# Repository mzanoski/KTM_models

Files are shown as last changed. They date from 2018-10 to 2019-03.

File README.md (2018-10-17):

# KTM 1290 OpenScad Models
This repo contains 3d models for 2017 KTM 1290 Super Adventure R accessories.  

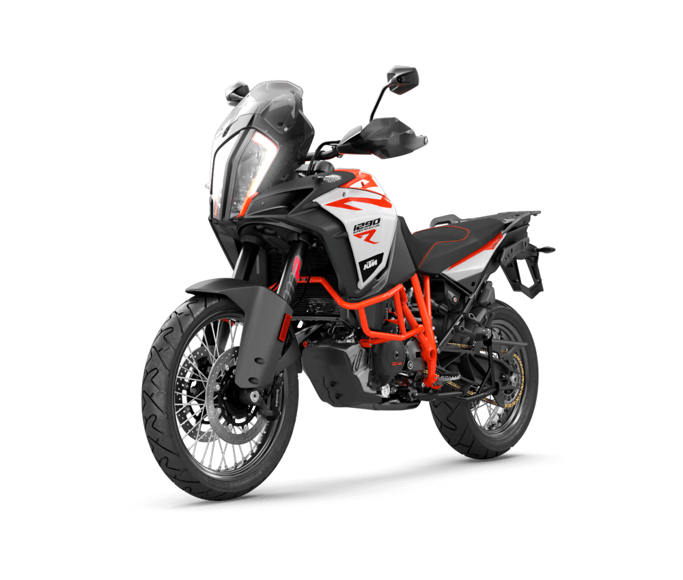
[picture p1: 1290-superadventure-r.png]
2017 KTM 1290 Super Adventure R Image


## Models
[Dash Accessory Bar](docs/dash_accessory_bar.md)\
[Dash GoPro Mount](docs/dash_gopro_mount.md)

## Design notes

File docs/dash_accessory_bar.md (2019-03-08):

# Dash Accessory Bar
This is an attachment with a grooved bar that can be attached to windshield bolt mounts above the dash screen.

## Definitions
These terms are used in scad file and are important for understanding parameters and how to make changes to your model.

| Item | Description |
| --- | --- |
| __Adapter__ | Conic portion of the attachment that is bolted to the top of the windscreen post |
| __Bar__ | Cylinder that stretches between the two windscreen mounts |
| __Bar Inner Hole__ | The hole inside of the bar used to insert aluminum tube or rod for additional strength |
| __Washer__ | Circle with a hole on the bolt side of the adapter |
| __End-Cap__ | Circle that covers the rider side of the adapter |
| __Cone__ | Conic shape between the washer and end-cap |
| __Anti-Roll Hole__ | Hole through the entire accessory bar for a pin that will prevent the bar from rolling |
| __Rick Bar__ | Grooved portion of the cylinder of the adapter |
| __Wall Thickness__ | Thickness of the washer, cone, and end-cap walls |
| __Margin__ | Tollerance added to windshield post side of the adapter and bar inner hole |

| Adapter | Bar |
| --- | --- |
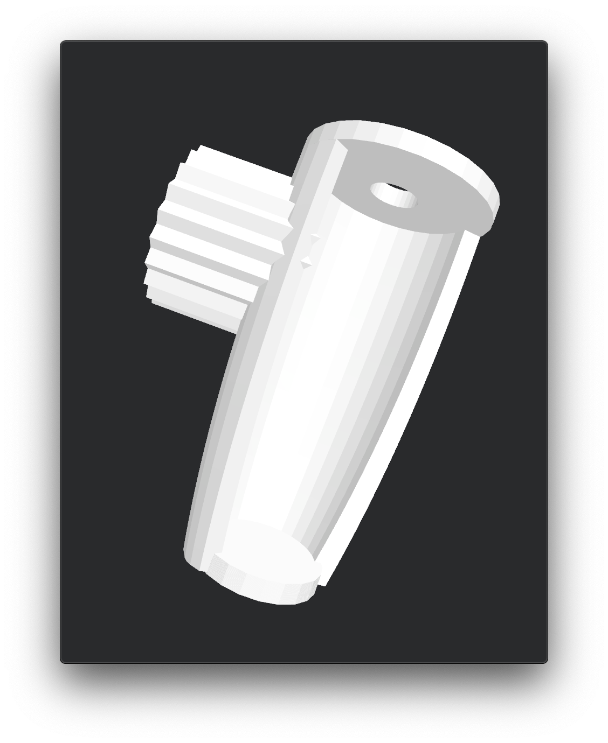
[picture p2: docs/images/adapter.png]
Adapter
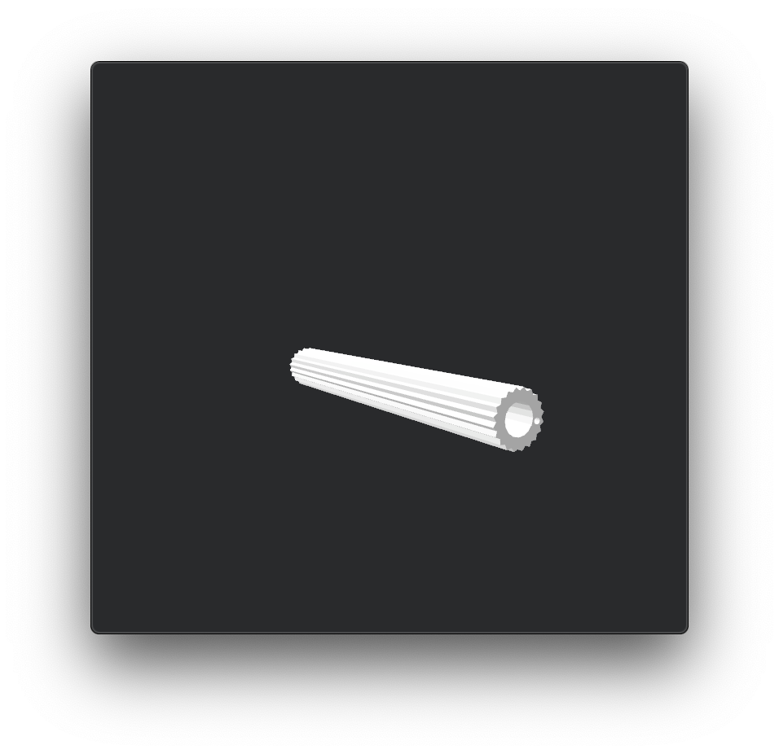
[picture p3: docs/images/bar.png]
Bar
| |  |

## Complete Accesory Bar
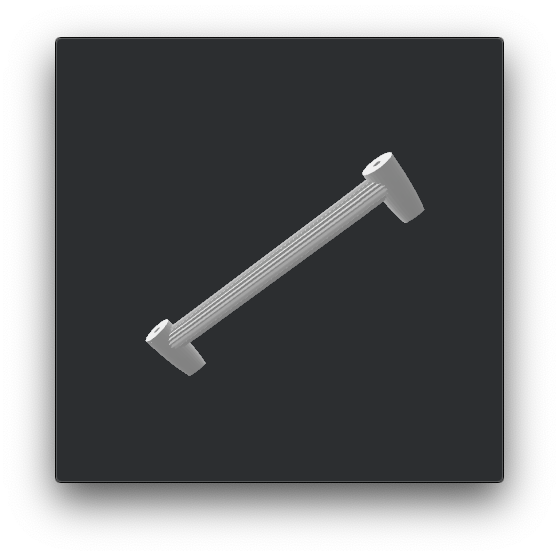
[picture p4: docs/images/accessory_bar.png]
Accessory Bar


## My Build Notes
1.  Leave the adapter a little, probably less than 0.5 mm, larger and lined the inside with two-sided outdoor carpet tape.  This results in a snug fit, prevents rattling, and end-cap lifting.

2.  Cut a thin nail to about 8mm and super-glue into anti-roll hole.  

3.  Size the bar inner hole to fit a light rod cut to appropritate length to the full length of the adapter.  This provides a lot of additional strength.

## Parameter Notes
__Note__: Values in this repo are the ones used on my build.

Parameters in the 'Module parameters' section of dash_accessory_bar_v1.scad should be pretty self explanatory.  They allow you to change most of the values needed to build the model.  

One exception to this is the bezier curve of the adapter cone.  Changes to cone length, washer diameter, or end diameter will require that the bezier curve parameters are adjusted manually.  Pay special attention to the warning section of the screen_post_adapter() module.  

All parameters that start with *prv_* are not meant to be modified when changing model parameters.  Only change these values if you're sure that they must be adjusted and you know exactly why.

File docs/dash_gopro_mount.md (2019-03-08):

# GoPro Mount
This is a simple mount that is designed to work with the [accessory bar](dash_accessory_bar.md).  If using default accessory bar values, you can use default mount parameter values as well.

## Definitions
This scad file uses the same parameter pattern as the accessory bar file.  It's important to understand that __BAR_Diameter__, __BAR_ToothDepth__, and __BAR_NumberOfTeeth__ values must match exactly the values used for the accessory bar in order to fit with each other.

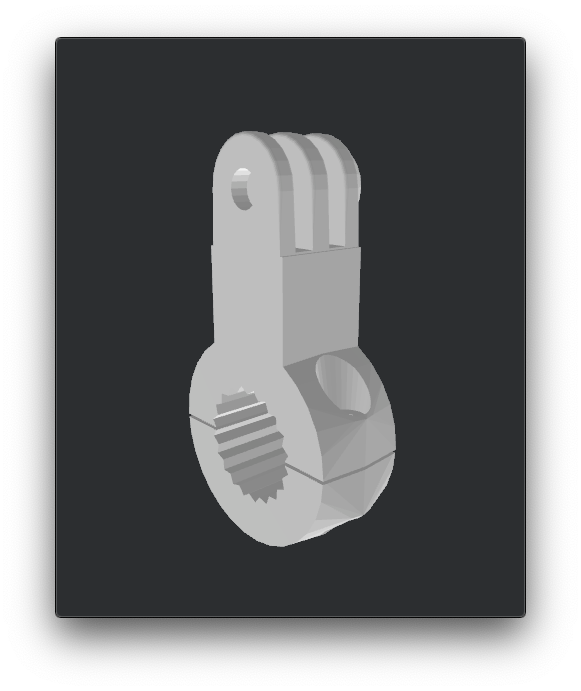
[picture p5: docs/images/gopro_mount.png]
gopro_mount


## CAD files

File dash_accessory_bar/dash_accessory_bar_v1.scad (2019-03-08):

 use <modules/washer.scad>
use <modules/quadriatic_bezier.scad>
use <modules/simple_gear.scad>

///////////////////////////// Module parameters /////////////////////////////
ADAPTER_Margin                          = 0.5;

// mid section cylinder - 'Rick' bar
BAR_Length                              = 173;
BAR_Diameter                            = 18;
BAR_InnerHoleDiameter                   = 9;
BAR_NumberOfTeeth                       = 20;
BAR_ToothDepth                          = 1;
BAR_AntiRollBarHoleDiameter             = 2;

// post adapter section
ADAPTER_WasherDiameter                  = 17.5;
ADAPTER_WasherHoleDiameter              = 5;
ADAPTER_WallThickness                   = 2;
ADAPTER_ConeLength                      = 40;
ADAPTER_EndDiameter                     = 9.5;

// post adapter - cylynder transition
ADAPTER_RickBarLength                   = 10;
ADAPTER_SmoothBarLength                 = 0;

//////////////////////// 'Private' Calculated Values ////////////////////////
// Rick bar section
prv_BarDiameter                 = BAR_Diameter;
prv_BarRadius                   = BAR_Diameter/2;
prv_BarInnerHoleDiameter        = BAR_InnerHoleDiameter+ADAPTER_Margin*2;
prv_BarInnerHoleRadius          = (BAR_InnerHoleDiameter/2)+ADAPTER_Margin;
prv_BarNumberOfTeeth            = BAR_NumberOfTeeth;
prv_BarToothDepth               = BAR_ToothDepth;
prv_BarMidSectionLength         = BAR_Length-2*ADAPTER_RickBarLength-2*ADAPTER_SmoothBarLength;

// post adapter section
prv_PostWallThickness           = ADAPTER_WallThickness;
prv_PostConeWasherSideRadius    = (ADAPTER_WasherDiameter+ADAPTER_Margin)/2;
prv_PostWasherOutterDiameter    = (prv_PostConeWasherSideRadius*2)+prv_PostWallThickness*2;
prv_PostWasherInnerDiameter     = ADAPTER_WasherHoleDiameter+ADAPTER_Margin;
prv_PostConeRiderSideRadius     = (ADAPTER_EndDiameter+ADAPTER_Margin)/2;
prv_PostConeRiderEndCapRadius   = prv_PostConeRiderSideRadius+0.5;
prv_PostConeLength              = ADAPTER_ConeLength+ADAPTER_Margin;
prv_PostSmoothBarLength         = ADAPTER_SmoothBarLength;
prv_PostRickBarLength           = ADAPTER_RickBarLength;

// Z and Y axis are same for every bar section
prv_BarZAxisPosition                = prv_BarRadius-prv_PostConeLength;
prv_PostSmoothBarZAxisPosition      = prv_BarRadius-prv_PostConeLength;
prv_PostRickBarZAxisPosition        = prv_BarRadius-prv_PostConeLength;

prv_BarYAxisPosition                = -prv_PostWallThickness;
prv_PostSmoothBarYAxisPosition      = -prv_PostWallThickness;
prv_PostRickBarYAxisPosition        = -prv_PostWallThickness+0.5;
// X-axis is different for every bar section
prv_PostSmoothBarXAxisPosition      = prv_PostWasherOutterDiameter/2;
prv_PostRickBarXAxisPosition        = prv_PostSmoothBarXAxisPosition+(prv_PostRickBarLength/2)+prv_PostSmoothBarLength;
prv_BarXAxisPosition                = prv_PostRickBarXAxisPosition+(prv_PostRickBarLength/2)+prv_BarMidSectionLength/2;

prv_PostRightAdapterXPosition       = 2*prv_PostConeWasherSideRadius+2*prv_PostRickBarLength+(2*prv_PostSmoothBarLength)+prv_BarMidSectionLength+2*prv_PostWallThickness;

// anti-roll bar
prv_BarAntiRollBarHoleRadius        = BAR_AntiRollBarHoleDiameter/2;
prv_BarAntiRollBarHoleLength        = BAR_Length+(prv_PostConeWasherSideRadius*2);
prv_BarAntiRollBarHoleYAxisPosition = prv_BarYAxisPosition-1;
prv_BarAntiRollBarHoleZAxisPosition = prv_BarZAxisPosition+prv_BarInnerHoleRadius+prv_BarAntiRollBarHoleRadius+0.5;


module screen_post_adapter(){
    union(){
        // ============ shape1: cone washer end ============
        translate([0,0,prv_PostConeLength+prv_PostWallThickness*2])
        rotate([0,90,0])
        washer(
            diameter_mm         = prv_PostWasherOutterDiameter,
            hole_diameter_mm    = prv_PostWasherInnerDiameter,
            thickness_mm        = prv_PostWallThickness,
            slice_angle         = [0,0,0]
        );

        // ============ shape2: cone body ============
        difference(){
            rotate([0,0,-165])
            color("yellow") bezier_cone(
                p0              = [prv_PostConeWasherSideRadius,prv_PostConeLength],
                p1              = [9,15],  // TODO: WARNING - this curve is not parametarized
                p2              = [prv_PostConeRiderSideRadius,-prv_PostWallThickness-ADAPTER_Margin],
                w               = prv_PostWallThickness,
                fill_degrees    = 215
            );
            translate([0,0,-prv_PostWallThickness*4])
            rotate([-16,0,0])
            color("red")
            cylinder(
                h   = prv_PostWallThickness*4,
                r1  = prv_PostConeRiderEndCapRadius*10,
                r2  = prv_PostConeRiderEndCapRadius*10
            );
        };

        // ============ shape3: cone rider end cap ============
        translate([0,0,prv_PostWallThickness+0.5])
        rotate([0,90,0])
        washer(
            diameter_mm         = prv_PostConeRiderEndCapRadius*2+prv_PostWallThickness,
            hole_diameter_mm    = 0,
            thickness_mm        = prv_PostWallThickness,
            slice_angle         = [0,0,-16]
        );
        
        // ============ shape4: smooth cylinder section ============
        rotate([0,90,0])
        translate([prv_PostSmoothBarZAxisPosition,prv_PostSmoothBarYAxisPosition,prv_PostSmoothBarXAxisPosition])
        color("yellow") 
        difference(){
            cylinder(
                h   = prv_PostSmoothBarLength, 
                r1  = prv_BarRadius, 
                r2  = prv_BarRadius
            );
            translate([0,0,prv_PostWallThickness])
            cylinder(
                h   = prv_PostSmoothBarLength, 
                r1  = prv_BarInnerHoleRadius, 
                r2  = prv_BarInnerHoleRadius
            );
        };

        // ============ shape5: grooved cylinder section ============
        rotate([0,90,0])
        translate([prv_PostRickBarZAxisPosition,prv_PostRickBarYAxisPosition,prv_PostRickBarXAxisPosition])
        color("yellow") simple_gear(
            cyl_length_mm           = prv_PostRickBarLength,
            cyl_diameter_mm         = prv_BarDiameter,
            center_hole_diameter    = prv_BarInnerHoleDiameter,
            num_of_teeth            = prv_BarNumberOfTeeth,
            groove_depth_mm         = prv_BarToothDepth
        );
    };

    // !!!!!!!!!!!!!!!!!!!!!!!!!!!!!!!!!!!!!!!!!!!!!!!!!!!!!!!!!!!!!!!!!!!!!!!!!!!!!!!!!!!!!!!!!!!!!!!!!!!!!
    // This section creates a cone that fills the inside of shape1 (cone body).  This is then used to
    // subtract the cylinder overvlow, (portion that went through the cone body), to create a fill shape  
    // that fills the space between shape1 and shape4.  

    // WARNING: Nothing about this section is parametarized and requries manual changes if any of the below
    //          module parameter values are changed:
    //          ADAPTER_WasherDiameter, ADAPTER_WasherHoleDiameter, ADAPTER_WallThickness, 
    //          ADAPTER_ConeLength,     ADAPTER_EndDiameter
    // !!!!!!!!!!!!!!!!!!!!!!!!!!!!!!!!!!!!!!!!!!!!!!!!!!!!!!!!!!!!!!!!!!!!!!!!!!!!!!!!!!!!!!!!!!!!!!!!!!!!!
    difference(){
        // ============ shape6: cone fill ============
        rotate([0,90,0])
        translate([prv_PostSmoothBarZAxisPosition,prv_PostRickBarYAxisPosition,prv_PostSmoothBarXAxisPosition-(prv_PostWallThickness*3.5)/2])
        color("blue") simple_gear(
            cyl_length_mm           = prv_PostWallThickness*3.5,
            cyl_diameter_mm         = prv_BarDiameter,
            center_hole_diameter    = prv_BarInnerHoleDiameter,
            num_of_teeth            = prv_BarNumberOfTeeth,
            groove_depth_mm         = prv_BarToothDepth
        );

        // ============ shape7: gap fill ============
        rotate([0,0,-135])
        color("red") bezier_cone(
            p0              = [prv_PostConeWasherSideRadius-5,prv_PostConeLength-3],
            p1              = [10-5.5,25],  // TODO: parametarize curve values
            p2              = [prv_PostConeRiderSideRadius-5,0],
            w               = prv_PostWallThickness+3,
            fill_degrees    = 360
        ); 
    };
}

module mid_bar(){
    // middle accessory attachment
    rotate([0,90,0])
    translate([prv_BarZAxisPosition,prv_BarYAxisPosition,prv_BarXAxisPosition]) 
    color("yellow")
    simple_gear(
        cyl_length_mm           = prv_BarMidSectionLength,
        cyl_diameter_mm         = prv_BarDiameter,
        center_hole_diameter    = prv_BarInnerHoleDiameter,
        num_of_teeth            = prv_BarNumberOfTeeth,
        groove_depth_mm         = prv_BarToothDepth
    );
}
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

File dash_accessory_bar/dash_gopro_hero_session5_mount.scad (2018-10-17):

use <modules/gopro_mounts_mooncactus.scad>
use <modules/simple_gear.scad>

///////////////////////////// Module parameters /////////////////////////////
BAR_Diameter                            = 18;
BAR_ToothDepth                          = 1;
BAR_NumberOfTeeth                       = 20;
CLAMP_Width                             = gopro_connector_z_func()*1.5;
CLAMP_Gap                               = 0.5;
POST_Height                             = 18;
POST_HoleRadius                         = gopro_connector_y_func()-5;

//////////////////////// 'Private' Calculated Values ////////////////////////
// Rick bar section
prv_goproGrooveDiameter         = BAR_Diameter;
prv_goproGrooveDepth            = BAR_ToothDepth;
prv_goproClampDiameter          = BAR_Diameter-BAR_ToothDepth-2;
prv_goproClampInnerToothNum     = BAR_NumberOfTeeth;
prv_goproClampWidth             = CLAMP_Width;
prv_gpproConnectorHeight        = 15.5;
prv_gporoPostHeight             = POST_Height;
prv_goproPostWidth              = gopro_connector_x_func()+1;
prv_goproPostDepth              = gopro_connector_y_func()+4.35;
prv_goproPostHoleRadius         = POST_HoleRadius;
prv_goproPostHoleHeight         = prv_gporoPostHeight;
prv_goproClampYPosition         = prv_gporoPostHeight;
prv_goproClampPadding           = 4;
prv_goproClampGap               = CLAMP_Gap;

module mount_clamp(){
    // clamp
    union(){
        translate([0,prv_goproClampYPosition,0])
        gopro_bar_clamp(
            rod_d= prv_goproClampDiameter+prv_goproClampPadding, // rod diameter
            th= 7, // main thickness
            gap= prv_goproClampGap, // space between the clamps
            screw_d= 3, // screw diameter
            screw_head_d= 6.2, // screw head diameter
            screw_nut_d= 6.01, // nut diameter from corner to corner
            screw_shoulder_th=6, // thickness of the shoulder on which the nut clamps
            screw_reversed=false	 // true to mirror the orientation of the clamp bolts
        );
        translate([0,prv_goproClampDiameter/2+gopro_connector_z_func()+prv_goproClampPadding/2+prv_goproClampYPosition,0])
        difference(){
            difference(){
                cylinder(r=prv_goproGrooveDiameter/2+2, h=prv_goproPostHoleHeight-3.3, center=true);
                // inner groove
                color("blue")
                simple_gear(
                    cyl_length_mm           = prv_goproClampWidth+1,
                    cyl_diameter_mm         = prv_goproGrooveDiameter,
                    center_hole_diameter    = 0,
                    num_of_teeth            = prv_goproClampInnerToothNum,
                    groove_depth_mm         = prv_goproGrooveDepth
                );
            }
            cube([(prv_goproClampDiameter+prv_goproClampPadding)*2,prv_goproClampGap,prv_goproPostDepth],center=true);
        }
    }
}

module mount_post(){
    color("blue")
    translate([0,prv_gpproConnectorHeight+2,0])
    cube([prv_goproPostWidth,prv_gporoPostHeight,prv_goproPostDepth],center=true);
}

module mount_inner_hole(){
    color("yellow")
    rotate([90,0,0])
    translate([0,0,-prv_gpproConnectorHeight/2-3-prv_goproPostHoleHeight])
    cylinder(r=prv_goproPostHoleRadius, h=prv_goproPostHoleHeight, center=false);
}

union(){
    gopro_connector("triple");
    // clamp
    translate([0,-2,0])
    mount_clamp();
    mount_post();
    mount_inner_hole();
}

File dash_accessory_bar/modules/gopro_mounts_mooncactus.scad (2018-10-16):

translate([-19,-15,-15.5])
  cube([38,30,5]);

/* [Main] */

// First head kind ("example" show them all but is not printable)
gopro_primary="triple"; // [example,triple,double]
// The other head kind (only for the triple or double primary kind)
gopro_secondary_what="clamp"; // [double,triple,rod,clamp,none]
// If ever you rotate the seconday head you will probably need to enable support to print it
gopro_secondary_rotated=0; // [0:false,1:true]

// Optional axis-to-axis extension rod (hence, it cannot be less than 20.7)
gopro_ext_len=28;
// The wall thickness of the extension rod (2 to 6mm are good values)
gopro_ext_th=3;

/* [Rod and captive nut] */

// This tab is useful only if you have selected "rod" as the secondary head. The optional rod diameter (also the captive nut internal diameter)
gopro_captive_rod_id= 3.8;
// The angle the rod makes with the axis (0 is colinear, 90 is a right angle)
gopro_captive_rod_angle= 45; // [0:90]
// Optional captive nut thickness with freeplay (tightest would be 3.2)
gopro_rod_nut_th= 3.6;
// Optional captive nut diameter with freeplay (from corner to corner)
gopro_rod_nut_od= 8.05;
// How much is the protruding output of the rod on the rod attachment (can be zero), useful if you don't want a captive nut with still a tight coupling
gopro_captive_protruding_h= 0.5;

/* [Clamp/bar mount] */

// This tab is useful only if you have selected "clamp" as the secondary head.  The optional (handle)bar diameter
gopro_bar_rod_d= 31;
// How thick is the ring around the bar
gopro_bar_th= 3.2;
// How big is the gap between the jaws
gopro_bar_gap= 2.4;
// The jaw screw diameter
gopro_bar_screw_d= 3;
// The diameter of the head of the screw
gopro_bar_screw_head_d= 6.2;
// The diameter of the nut of the screw from corner to corner (can be zero)
gopro_bar_screw_nut_d= 6.01;
// How thick are the shoulders on which to bolt (each side)
gopro_bar_screw_shoulder_th=4.5;
// Whether to reverse the bolt orientation (from which side you will screw the bolt, defaut is from the joint)
gopro_bar_screw_reversed=false; // [true,false]

/* [Hidden] */

// The gopro connector itself (you most probably do not want to change this but for the first two)

// The locking nut on the gopro mount triple arm mount (keep it tight)
gopro_nut_d= 9.2;
// How deep is this nut embossing (keep it small to avoid over-overhangs)
gopro_nut_h= 2;
// Hole diameter for the two-arm mount part
gopro_holed_two= 5;
// Hole diameter for the three-arm mount part
gopro_holed_three= 5.5;
// Thickness of the internal arm in the 3-arm mount part
gopro_connector_th3_middle= 3.1;
// Thickness of the side arms in the 3-arm mount part
gopro_connector_th3_side= 2.7;
// Thickness of the arms in the 2-arm mount part
gopro_connector_th2= 3.04;
// The gap in the 3-arm mount part for the two-arm
gopro_connector_gap= 3.1;
// How round are the 2 and 3-arm parts
gopro_connector_roundness= 1;
// How thick are the mount walls
gopro_wall_th= 3;

gopro_connector_wall_tol=0.5+0;
gopro_tol=0.04+0;

// Can be queried from the outside
gopro_connector_z= 2*gopro_connector_th3_side+gopro_connector_th3_middle+2*gopro_connector_gap;
gopro_connector_x= gopro_connector_z;
gopro_connector_y= gopro_connector_z/2+gopro_wall_th;

function gopro_connector_z_func() = 2*gopro_connector_th3_side+gopro_connector_th3_middle+2*gopro_connector_gap;
function gopro_connector_x_func() = gopro_connector_z;
function gopro_connector_y_func() = gopro_connector_z/2+gopro_wall_th;

///////////////////////////////////////////////////////////////////////
//
// GoPro Hero mount and joint (gopro_mounts_mooncactus.scad) - Rev 1.03
//
///////////////////////////////////////////////////////////////////////
//
// CC-BY-NC 2013 jeremie.francois@gmail.com
// http://www.thingiverse.com/thing:62800
// http://betterprinter.blogspot.com
//

// It slices neatly on an ultimaker with the following parameters
//
// 0.1 mm layers (for better look & more compact FDM) -- 0.15 is still OK (and faster)
// 0.8 mm walls (loops->infill->perimeters)
// 0.8 mm bottom/top
// 100% fill (probably safer, though 30% is quite OK)
//
// Rev 1.01: fixed printing angle vs captive nut slot, added a slight freeplay
// Rev 1.02: added handle/bar mount and rounded the angles of the rod mount
// Rec 1.03: examples and first release (20130317-1234)

/* ****************************************************************

HOW TO USE IN YOUR OWN DESIGNS

use <gopro_mounts_mooncactus.scad>

// Create a "triple" gopro connector
gopro_connector("triple");

// Create a "triple" gopro connector without the locking nut shape
translate([30,0,0])
	gopro_connector("triple", withnut=false);

// Create a "double" gopro connector
translate([60,0,0])
	gopro_connector("double");

// Add a bar mount/clamp to one of the connector
translate([90,0,0])
gopro_bar_clamp(
	rod_d= 31, // rod diameter
	th= 3.2, // main thickness
	gap= 2.4, // space between the clamps
	screw_d= 3, // screw diameter
	screw_head_d= 6.2, // screw head diameter
	screw_nut_d= 6.01, // nut diameter from corner to corner
	screw_shoulder_th=4.5, // thickness of the shoulder on which the nut clamps
	screw_reversed=false	 // true to mirror the orientation of the clamp bolts
);

// Extends a connector with a mount for a rod and an optional embedded nut
translate([120,0,0])
gopro_rod_connect(
	rod_id=3.8, // rod diameter
	angle=80,  // rod angle (0 is straight, 90 is a right turn)
	nut_th=3.2, // embedded nut thickness (can be zero to disable the embedded nut)
	nut_od=7.9 // nut diameter from corner to corner
);

// How to build a linear extruded bar extender
translate([0,65,0])
{
	gopro_connector("double");
	gopro_extended(len=50, th=3)
		scale([1,-1,1])
				gopro_connector("triple");
}

// The following dimensions are useful to attach the mount to your design:
	gopro_connector_z= 14.7;
	gopro_connector_x= 14.7;
	gopro_connector_y= 10.35;


// Finally, note that the arm are designed in a way which is not the best orientation to print: you would better rotate them with, eg. rotate([0,90,0])

**************************************************************** */



// To generate the sample set in bash, just copy/paste the following in a terminal:
/*
for kind in double triple; do
	for angle in 30 80; do
		through=true
		[[ $angle == 0 ]] && through=false
		openscad -D print_it=true -D gopro_primary="\"$kind\"" -D gopro_captive_rod_angle=$angle -o gmb_${kind}_${angle}.stl gopro_mount_bit.scad
	done
	openscad -D print_it=true -D gopro_primary="\"$kind\"" -D gopro_rod_nut_th=0 -o gmb_${kind}_simple.stl gopro_mount_bit.scad
done
*/


//
// ================ Full (colored) example (for openscad & command line)
//
gopro_ext_len_real= (gopro_ext_len > 2*gopro_connector_y ? gopro_ext_len : 0);
if(gopro_primary=="example")
{
	gopro_connector("triple", withnut=true);
	
	color([1,0.2,0.2])
		gopro_bar_clamp(
			rod_d= gopro_bar_rod_d, th=gopro_bar_th, gap=gopro_bar_gap,
			screw_d= gopro_bar_screw_d, screw_head_d= gopro_bar_screw_head_d, screw_nut_d= gopro_bar_screw_nut_d, screw_shoulder_th= gopro_bar_screw_shoulder_th,
			screw_reversed= gopro_bar_screw_reversed	);
			
	rotate([0,180,130]) color([0.2,0.2,1])
		gopro_connector("double");
		
	rotate([0,180,130]) color([0,0.8,0])
		gopro_rod_connect(nut_th=gopro_rod_nut_th, nut_od=gopro_rod_nut_od, rod_id=gopro_captive_rod_id, angle=gopro_captive_rod_angle);

	translate([-35,-10,0]) color([0.6,0.6,0.6])
	rotate([0,0,10])
	{
		gopro_connector("double");
		gopro_extended(len=gopro_ext_len, th=gopro_ext_th)
		{
			scale([1,-1,1])	gopro_connector("triple");
			// or (eg.)
//			translate([0,-2*gopro_connector_y,0]) gopro_bar_clamp(rod_d= 20, th= 5, gap= 5, screw_d= 3, screw_head_d= 6.2, screw_nut_d= 6.01, screw_shoulder_th=4.5, screw_reversed=true);
		}
	}
}
else // useful blocks
{
	//
	// ================ Printable standalone blocks (for the customizer)
	//
	rotate([-90,0,0])
	{
		if(gopro_primary=="triple")
			gopro_connector("triple", withnut=true);
		else
			gopro_connector("double");
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

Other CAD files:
dash_accessory_bar/modules/quadriatic_bezier.scad
dash_accessory_bar/modules/simple_gear.scad
dash_accessory_bar/modules/washer.scad

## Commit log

2018-10-07 grooved middle section
    [publicDomainGearV1.1.scad]
2018-10-07 oops, forgot the changes :)
    [grooved_cylinder.scad]
2018-10-08 add washer util, refactor, and some cleanup
    [grooved_cylinder.scad, screen_holder_adapters.scad, simple_gear.scad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]
2018-10-09 much more elegant when using extrusions + translations
    [publicDomainGearV1.1.scad, simple_gear.scad, washer.scad]
2018-10-09 adding bezier_cone
    [quadratic_bezier.scad]
2018-10-09 initial accessory adapter model + reorg and clean up files
    [accessory_adapter_v1.scad, quadratic_bezier.scad, screen_holder_adapters.scad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]
2018-10-09 parametarized much of the model, added tollerance variable, etc. A few todos too.
    [accessory_adapter_v1.scad]
2018-10-10 global $fn setting not required
    [accessory_adapter_v1.scad, simple_gear.scad]
2018-10-10 file name misspelled
    [quadriatic_bezier.scad]
2018-10-10 import fix after module file name change, remove 'FN', bunch of docs and reorg
    [dash_accessory_bar_v1.scad]
2018-10-11 adjust end-cap angle, spacing, and clean up cone overhang over end-cap
    [dash_accessory_bar_v1.scad]
2018-10-12 dialing in dimensions and doc updates
    [dash_accessory_bar_v1.scad]
2018-10-16 removing todos
    [dash_accessory_bar_v1.scad]
2018-10-16 gopro mount initial commit
    [gopro_hero_session5_mount.scad, gopro_mounts_mooncactus.scad]
2018-10-17 mount size adjustments
    [gopro_hero_session5_mount.scad]
2018-10-17 rename the gopro mount file
    [dash_gopro_hero_session5_mount.scad]
2019-03-08 add gopro mount image
    [dash_accessory_bar_v1.scad]
